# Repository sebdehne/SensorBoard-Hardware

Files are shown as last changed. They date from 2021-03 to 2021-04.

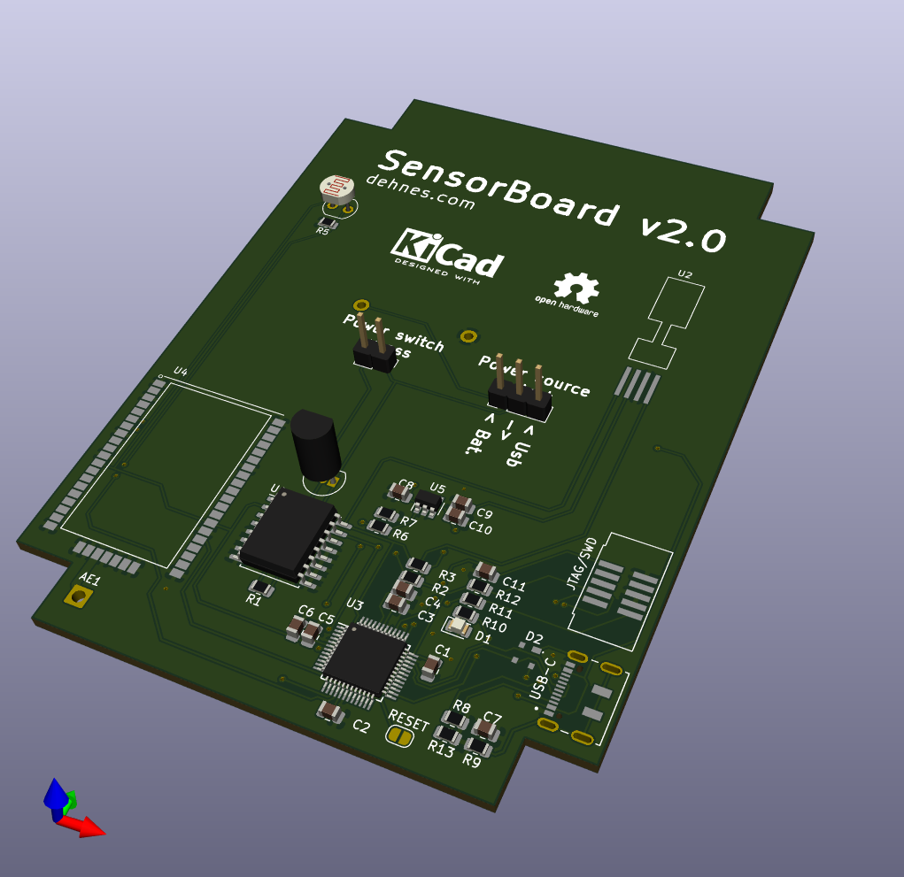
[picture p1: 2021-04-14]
images/3d-view.png

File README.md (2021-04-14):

# RoomSensorV2-Hardware
KiCad design files for my RoomSensorV2 - a battery power, wireless, environment sensor 

- [Temperature, humidity](https://www.amphenol-sensors.com/en/telaire/humidity/527-humidity-sensors/3095-chipcap-2) and light sensor
- ARM® Cortex®-M0+ based atsamd21g18a microcontroller (way overkill of course, but easier to program than a tiny 8-bit micro)
- [RN2483](https://www.microchip.com/wwwproducts/en/RN2483) LoRa wireless module
- Uses external RTC [DS3231SN#](https://no.mouser.com/ProductDetail/Maxim-Integrated/DS3231SN?qs=1eQvB6Dk1vhUlr8%2FOrV0Fw%3D%3D) to cut power to all components to achieve ~0.9µA sleep current
- USB-C for easy firmware updates - which are not really needed because I am going to implement over-the-air firmware updates

See [Schematic](images/schematic.pdf) and [3d-view](images/3d-view.png).

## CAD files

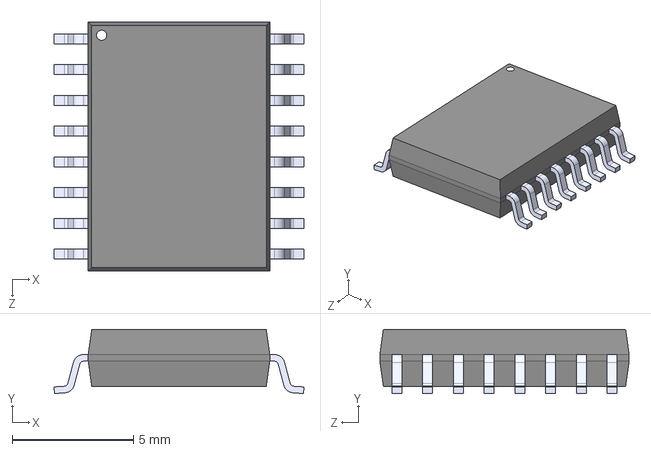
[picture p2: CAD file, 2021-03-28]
symbols/DS3231SN_.step
10.3 x 2.65 x 10.3 mm

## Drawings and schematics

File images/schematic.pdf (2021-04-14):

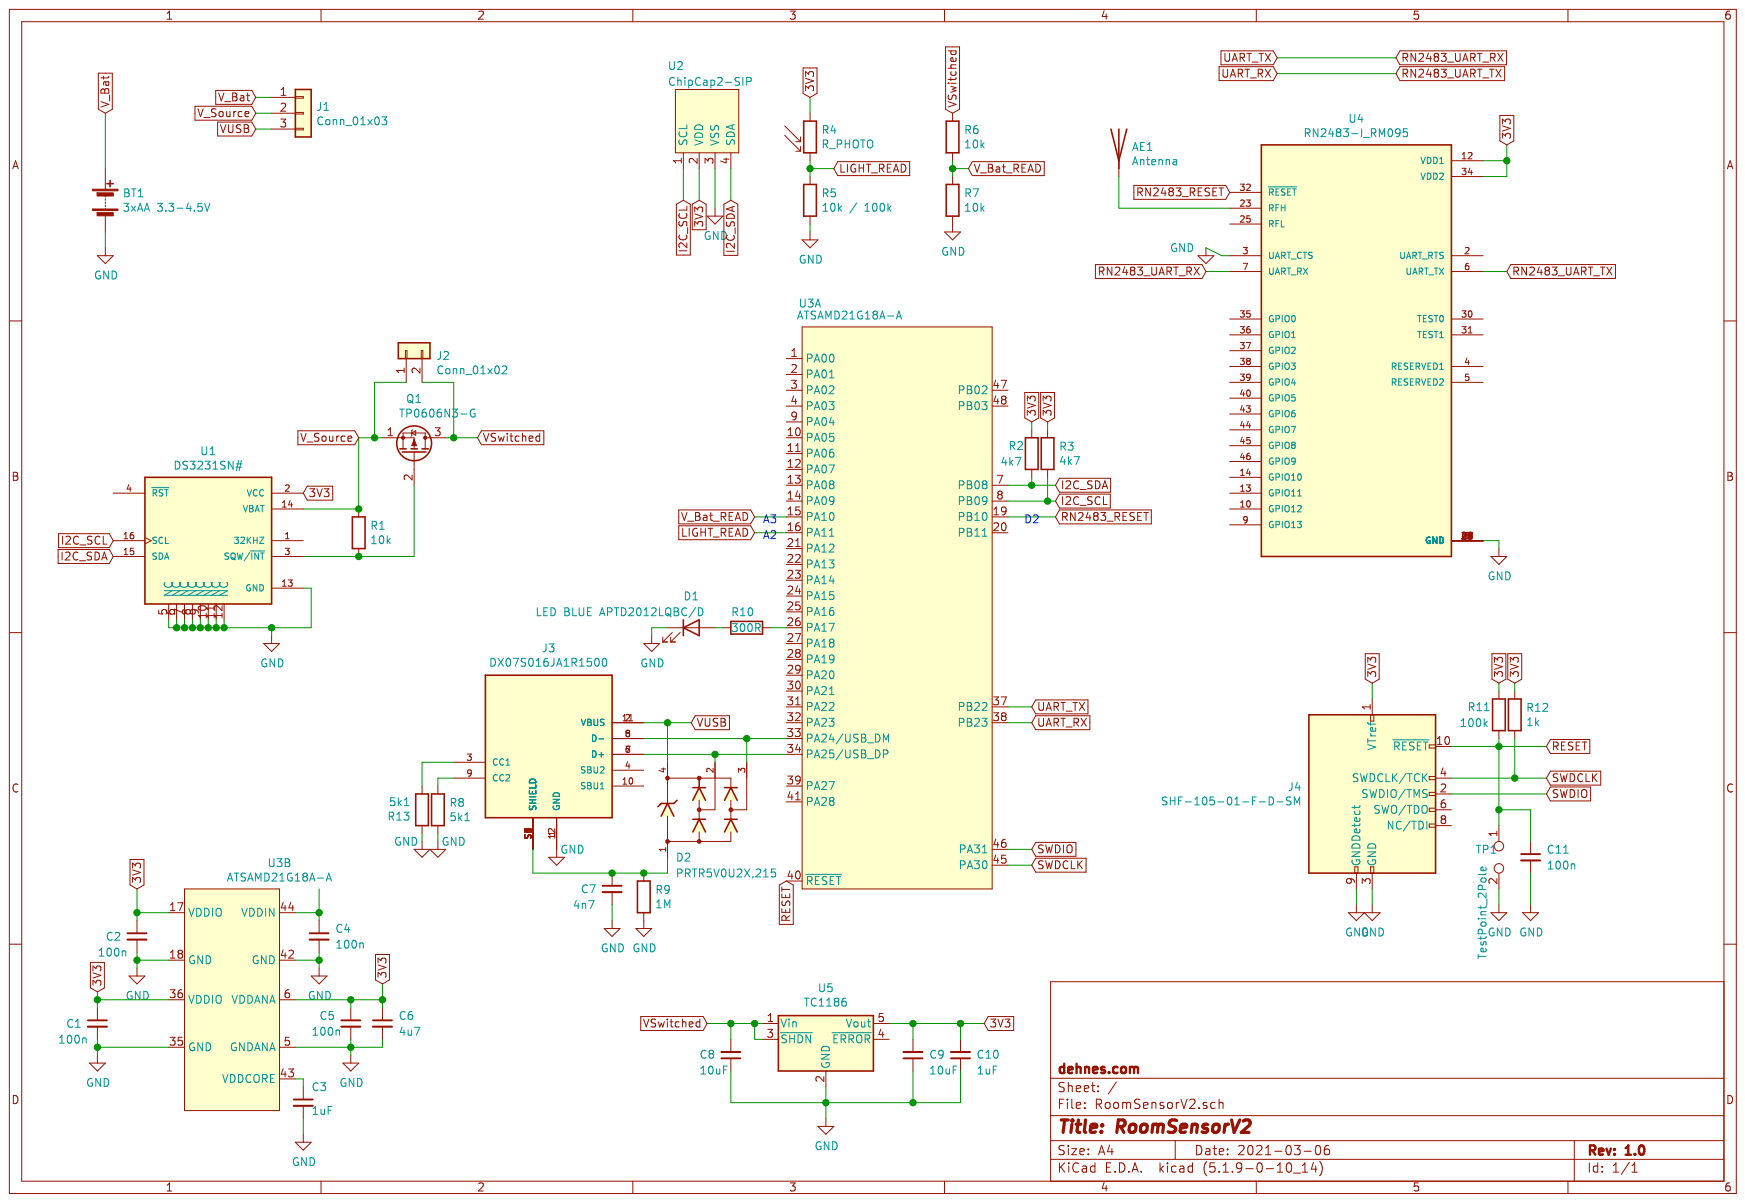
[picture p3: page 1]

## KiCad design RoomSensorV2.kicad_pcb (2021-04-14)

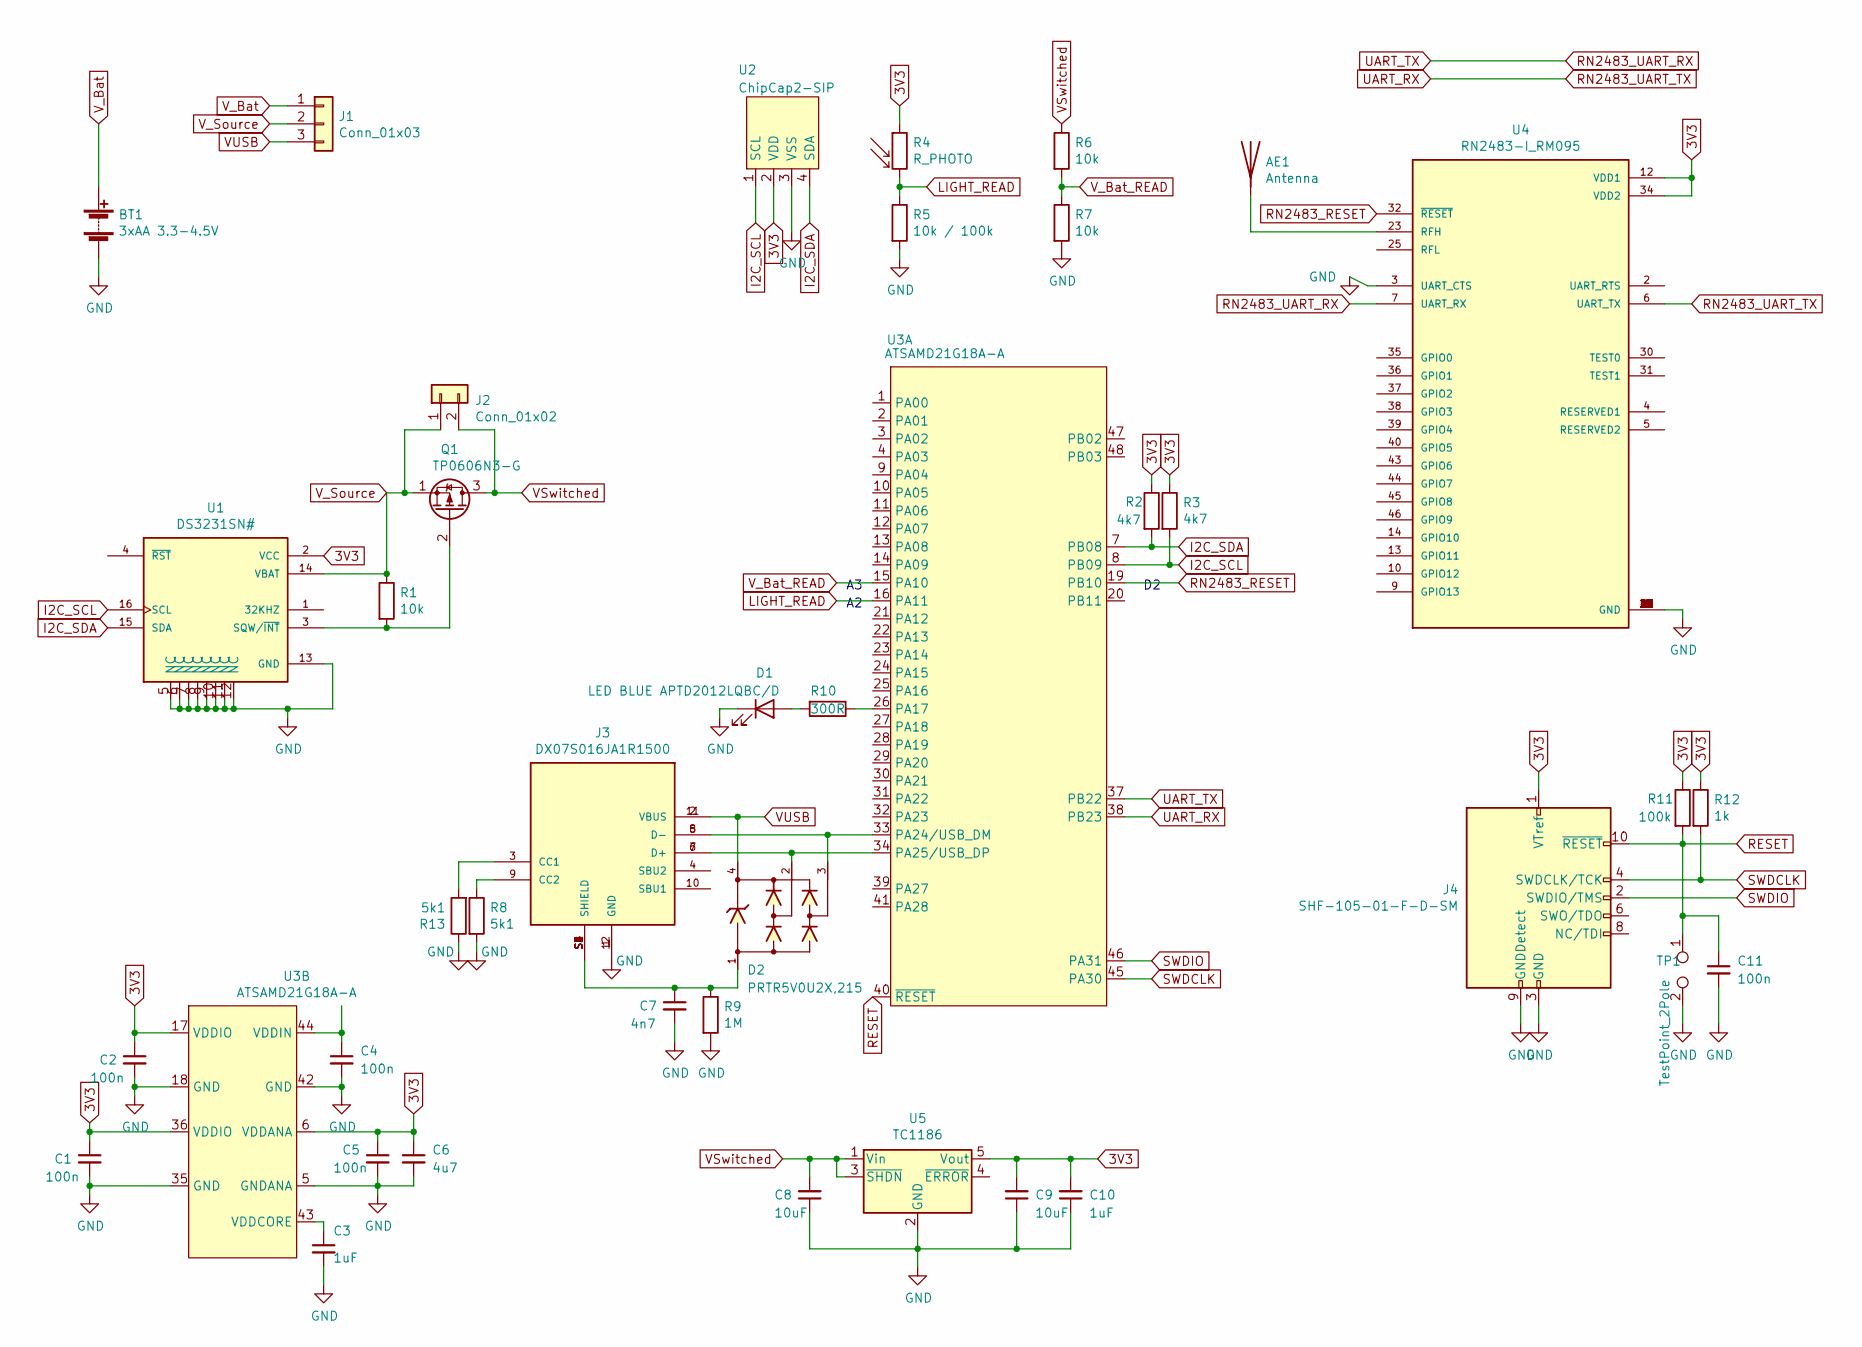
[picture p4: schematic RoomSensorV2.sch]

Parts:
AE1: Antenna; SolderWire-0.75sqmm_1x01_D1.25mm_OD2.3mm
BT1: 3xAA 3.3-4.5V; Battery_holder_3xAA
C1, C2, C4, C5, C11: 100n; C_0805_2012Metric
C3, C10: 1uF; C_0805_2012Metric
C6: 4u7; C_0805_2012Metric
C7: 4n7; C_0805_2012Metric
C8, C9: 10uF; C_0805_2012Metric
D1: LED BLUE APTD2012LQBC/D; LED_0805_2012Metric
D2: PRTR5V0U2X,215; SOT143B
J1: Conn_01x03; PinHeader_1x03_P2.54mm_Vertical
J2: Conn_01x02; PinHeader_1x02_P2.54mm_Vertical
J3: DX07S016JA1R1500; JAE_DX07S016JA1R1500; PARTREV 1
J4: SHF-105-01-F-D-SM; SHF-105-01-X-D-SM
Q1: TP0606N3-G; TO-92L_Inline
R1, R6, R7: 10k; R_0805_2012Metric
R2, R3: 4k7; R_0805_2012Metric
R4: R_PHOTO; R_LDR_4.9x4.2mm_P2.54mm_Vertical
R5: 10k / 100k; R_0805_2012Metric
R8, R13: 5k1; R_0805_2012Metric
R9: 1M; R_0805_2012Metric
R10: 300R; R_0805_2012Metric
R11: 100k; R_0805_2012Metric
R12: 1k; R_0805_2012Metric
TP1: TestPoint_2Pole; SolderJumper-2_P1.3mm_Open_RoundedPad1.0x1.5mm
U1: DS3231SN#; SOIC-16W_7.5x10.3mm_P1.27mm
U2: ChipCap2-SIP; ChipCap2SIP
U3: ATSAMD21G18A-A; TQFP-48_7x7mm_P0.5mm
U4: RN2483-I_RM095; RM095
U5: TC1186; SOT-23-5

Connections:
3V3: C1.1, C2.1, C5.1, C6.1, C9.2, C10.2, J4.1 (VTref), R2.1, R3.1, R4.1, R11.1, R12.1, U1.2 (VCC), U2.2 (VDD), U3.6 (VDDANA), U3.17 (VDDIO), U3.36 (VDDIO), U4.12 (VDD1), U4.34 (VDD2), U5.5 (Vout); also elsewhere on the board
GND: BT1.2 (-), C1.2, C2.2, C3.2, C4.2, C5.2, C6.2, C7.2, C8.1, C9.1, C10.1, C11.2, D1.1 (K), J3.1 (GND), J3.12 (GND), J4.3 (GND), J4.5 (GND), J4.9 (GNDDetect), R5.2, R7.2, R8.2, R9.2, R13.1, TP1.2, U1.5 (NC), U1.6 (NC), U1.7 (NC), U1.8 (NC), U1.9 (NC), U1.10 (NC), U1.11 (NC), U1.12 (NC), U1.13 (GND), U2.3 (VSS), U3.5 (GNDANA), U3.18 (GND), U3.35 (GND), U3.42 (GND), U4.1 (GND), U4.3 (UART_CTS), U4.8 (GND), U4.11 (GND), U4.20 (GND), U4.21 (GND), U4.22 (GND), U4.24 (GND), U4.26 (GND), U4.27 (GND), U4.28 (GND), U4.33 (GND), U4.41 (GND), U4.47 (GND), U5.2 (GND); also elsewhere on the board
I2C_SCL: R3.2, U1.16 (SCL), U2.1 (SCL), U3.8 (PB09)
I2C_SDA: R2.2, U1.15 (SDA), U2.4 (SDA), U3.7 (PB08)
LIGHT_READ: R4.2, R5.1, U3.16 (PA11)
unnamed: AE1.1, U4.23 (RFH)
unnamed: C3.1, U3.43 (VDDCORE)
unnamed: C4.1, U3.44 (VDDIN)
unnamed 8: C7.1, D2.1, J3.S1 (SHIELD), J3.S2 (SHIELD), J3.S3 (SHIELD), J3.S4 (SHIELD), J3.S5 (SHIELD), J3.S6 (SHIELD), R9.1; also elsewhere on the board
unnamed: D1.2 (A), R10.2
unnamed 10: D2.2, J3.6 (D+), J3.7 (D+), U3.34 (PA25/USB_DP); also elsewhere on the board
unnamed 11: D2.3, J3.5 (D-), J3.8 (D-), U3.33 (PA24/USB_DM); also elsewhere on the board
unnamed 12: J3.3 (CC1), R13.2; also elsewhere on the board
unnamed 14: J3.9 (CC2), R8.1; also elsewhere on the board
unnamed: Q1.2 (G), R1.2, U1.3 (SQW/~INT)
unnamed: R10.1, U3.26 (PA17)
RESET: C11.1, J4.10 (~RESET~), R11.2, TP1.1, U3.40 (~RESET); also elsewhere on the board
RN2483_RESET: U3.19 (PB10), U4.32 (~RESET)
RN2483_UART_RX: U3.37 (PB22), U4.7 (UART_RX)
RN2483_UART_TX: U3.38 (PB23), U4.6 (UART_TX)
SWDCLK: J4.4 (SWDCLK/TCK), R12.2, U3.45 (PA30); also elsewhere on the board
SWDIO: J4.2 (SWDIO/TMS), U3.46 (PA31); also elsewhere on the board
VSwitched: C8.2, J2.2, Q1.3 (D), R6.1, U5.1 (Vin), U5.3 (~SHDN)
VUSB: D2.4, J1.3, J3.2 (VBUS), J3.11 (VBUS); also elsewhere on the board
V_Bat: BT1.1 (+), J1.1
V_Bat_READ: R6.2, R7.1, U3.15 (PA10)
V_Source: J1.2, J2.1, Q1.1 (S), R1.1, U1.14 (VBAT)

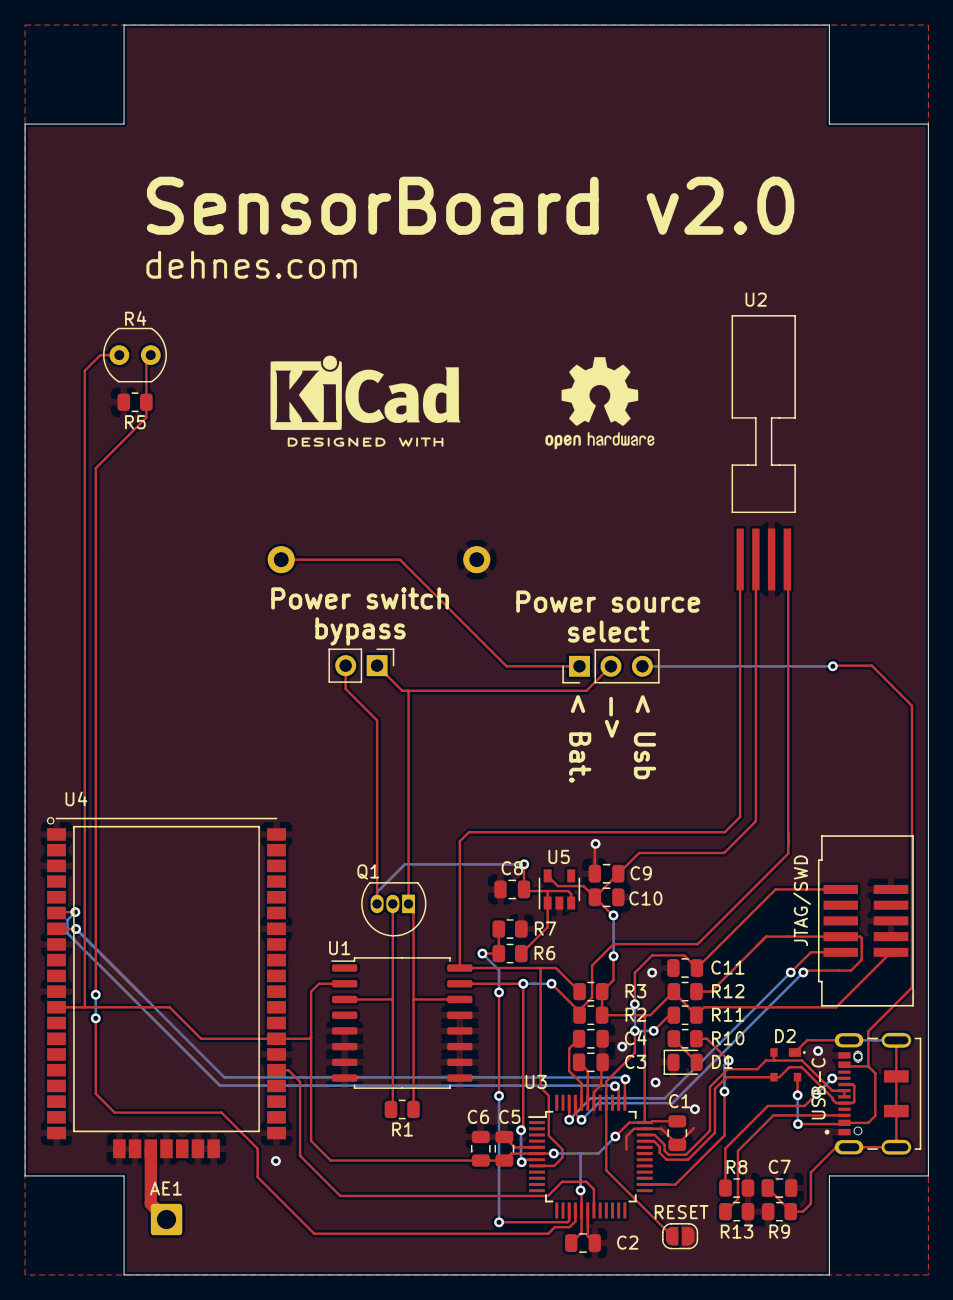
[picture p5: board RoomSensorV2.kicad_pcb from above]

Board: 2 copper layers, 73.0 x 101.0 mm, 39 parts (1 on the bottom side), 27 nets.

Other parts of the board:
JTAG/SWD: SHF-105-01-F-D-SM; SHF-105-01-X-D-SM
RESET: TestPoint_2Pole; SolderJumper-2_P1.3mm_Open_RoundedPad1.0x1.5mm
USB-C: DX07S016JA1R1500; JAE_DX07S016JA1R1500

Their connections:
3V3: JTAG/SWD.1; also elsewhere on the board
GND: JTAG/SWD.3, JTAG/SWD.5, JTAG/SWD.9, RESET.2, USB-C.1, USB-C.12; also elsewhere on the board
unnamed 8: USB-C.S1, USB-C.S2, USB-C.S3, USB-C.S4, USB-C.S5, USB-C.S6; also elsewhere on the board
unnamed 10: USB-C.6, USB-C.7; also elsewhere on the board
unnamed 11: USB-C.5, USB-C.8; also elsewhere on the board
unnamed 12: USB-C.3; also elsewhere on the board
unnamed 14: USB-C.9; also elsewhere on the board
RESET: JTAG/SWD.10, RESET.1; also elsewhere on the board
SWDCLK: JTAG/SWD.4; also elsewhere on the board
SWDIO: JTAG/SWD.2; also elsewhere on the board
VUSB: USB-C.2, USB-C.11; also elsewhere on the board

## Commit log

2021-03-28 added PCB
    [RoomSensorV2.sch]
2021-04-11 Replaced Seeeduino XIAO by using ATSAMD21G18A microcontroller directly
    [RoomSensorV2.sch]
2021-04-14 Revision 1.0
    [RoomSensorV2.kicad_pcb, RoomSensorV2.sch]
2021-05-02 added datasheet link
    [RoomSensorV2.sch]
